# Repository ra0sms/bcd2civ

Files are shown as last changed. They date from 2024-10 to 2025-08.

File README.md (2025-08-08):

## Converter Yaesu BCD to Icom CI-V band data

A simple board is based on risk-v MCU CH32V003F4P6. 

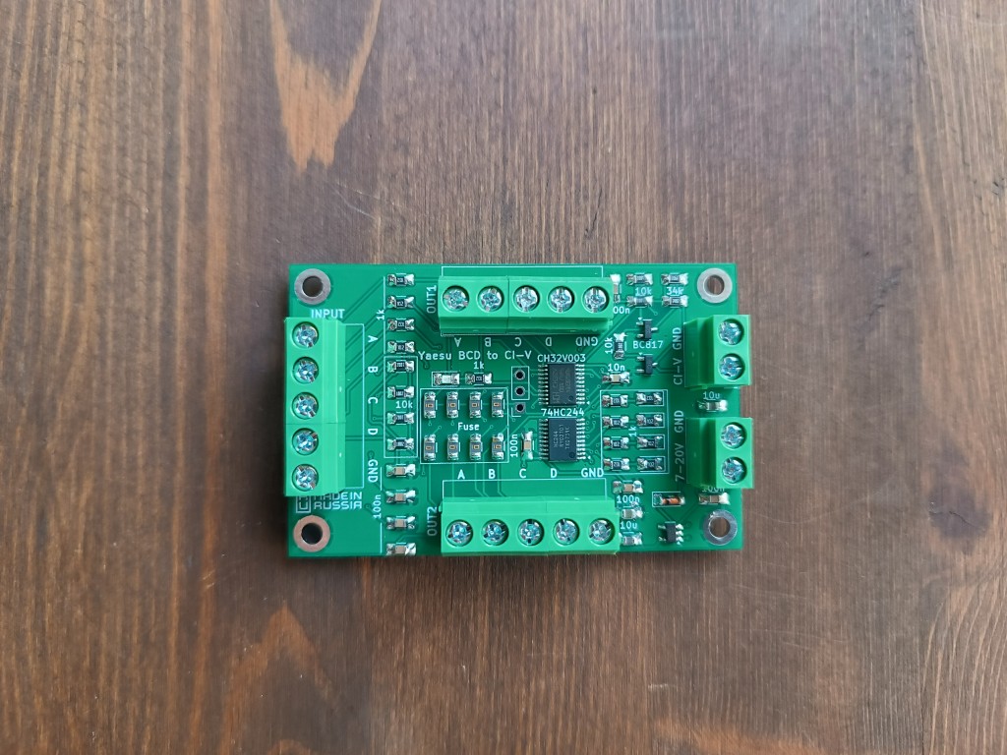
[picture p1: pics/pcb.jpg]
pcb


* Dimensions: 70*45 mm
* Consumption current: 20 mA
* Power supply: from 7 to 20VDC
* CI-V address: 0x7A
* Baud rate for EW3MM tuner: 9600 kb/s
* Baud rate for DJ0ABR controller: 4800 kb/s

[Firmware for EU3MM tuner](code/obj/bcd2civ_tuner.hex)

[Firmware for DJ0ABR controller](code/obj/bcd2civ_dj0abr.hex)

More information - https://ra0sms.com/bcd2civ

### Yaesu BCD band data:

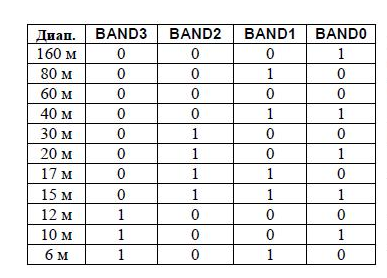
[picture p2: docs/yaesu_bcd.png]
yaseu_bcd


### Schematic:

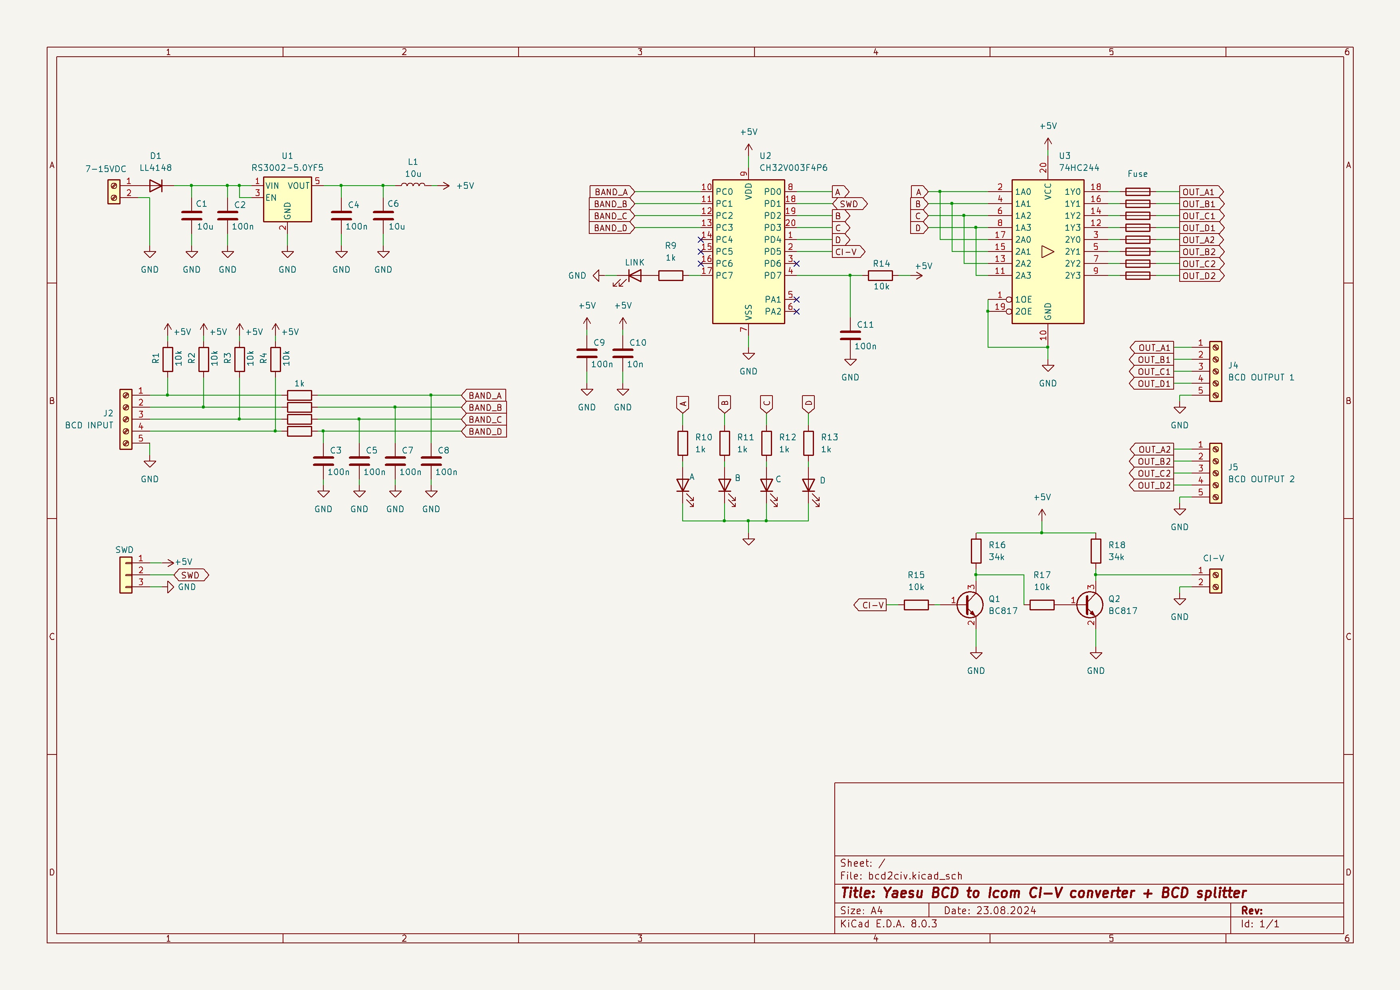
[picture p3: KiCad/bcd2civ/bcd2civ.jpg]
bcd2civ


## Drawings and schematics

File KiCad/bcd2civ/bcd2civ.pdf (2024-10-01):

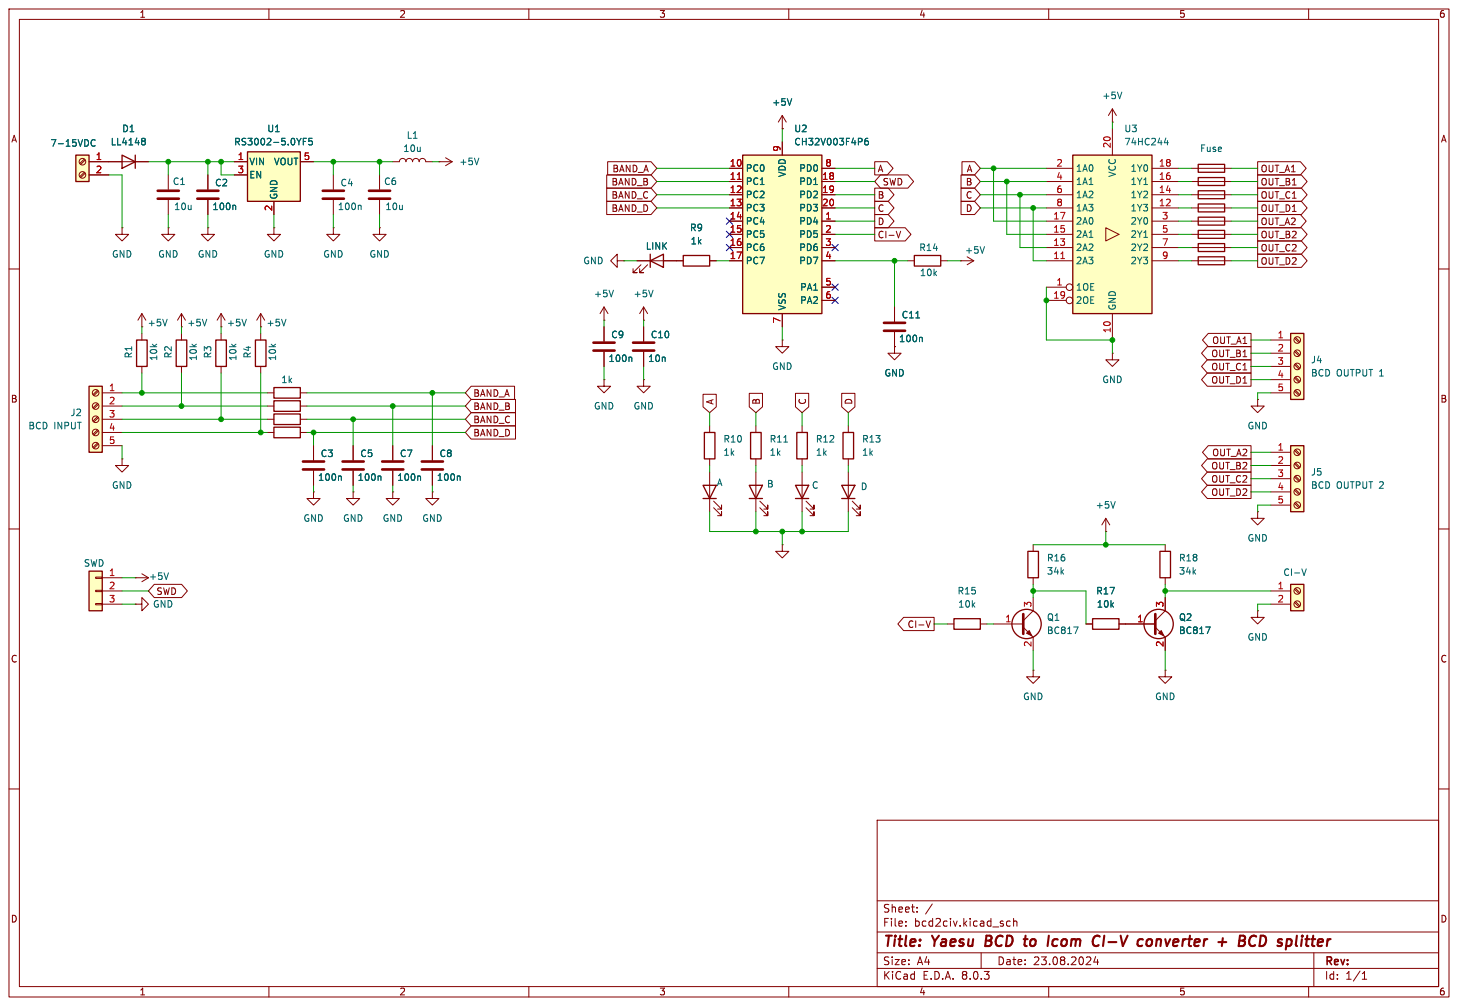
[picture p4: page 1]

Id: 1/1 Title: Yaesu BCD to Icom CI-V converter + BCD splitter File: bcd2civ.kicad_sch Sheet: /

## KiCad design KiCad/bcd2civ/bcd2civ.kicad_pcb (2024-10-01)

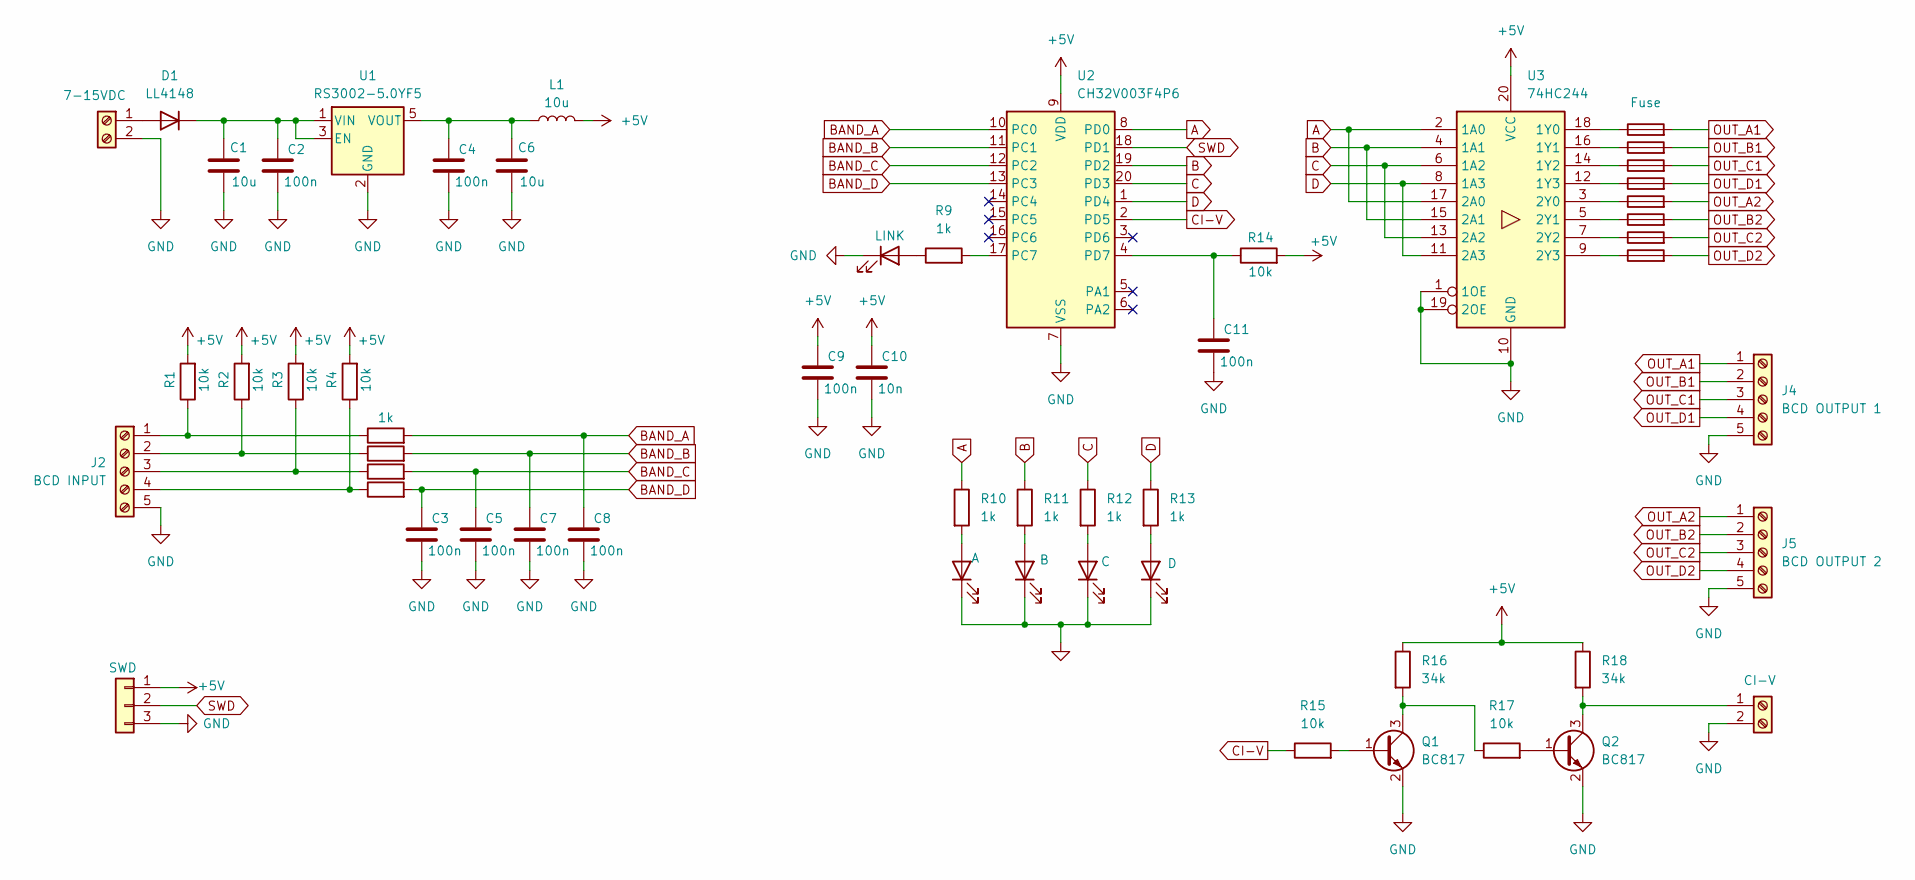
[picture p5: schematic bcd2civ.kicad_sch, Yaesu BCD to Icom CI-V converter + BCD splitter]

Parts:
C1, C6: 10u; C_1206_3216Metric_Pad1.33x1.80mm_HandSolder
C2, C3, C4, C5, C7, C8, C9, C11: 100n; C_1206_3216Metric_Pad1.33x1.80mm_HandSolder
C10: 10n; C_1206_3216Metric_Pad1.33x1.80mm_HandSolder
D1: LL4148; D_MiniMELF
D2: LINK; LED_1206_3216Metric
D3: A; LED_1206_3216Metric
D4: B; LED_1206_3216Metric
D5: C; LED_1206_3216Metric
D6: D; LED_1206_3216Metric
F1, F2, F3, F4, F5, F6, F7, F8: Fuse; R_1206_3216Metric
J1: 7-15VDC; TerminalBlock_MetzConnect_Type055_RT01502HDWU_1x02_P5.00mm_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
J2: BCD INPUT; TerminalBlock_MetzConnect_Type011_RT05505HBWC_1x05_P5.00mm_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
J3: SWD; PinSocket_1x03_P2.54mm_Vertical
J4: BCD OUTPUT 1; TerminalBlock_MetzConnect_Type011_RT05505HBWC_1x05_P5.00mm_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
J5: BCD OUTPUT 2; TerminalBlock_MetzConnect_Type011_RT05505HBWC_1x05_P5.00mm_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
J6: CI-V; TerminalBlock_MetzConnect_Type055_RT01502HDWU_1x02_P5.00mm_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
L1: 10u; L_1206_3216Metric
Q1, Q2: BC817; SOT-23
R1, R2, R3, R4, R14, R15, R17: 10k; R_1206_3216Metric
R5, R6, R7, R8, R9, R10, R11, R12, R13: 1k; R_1206_3216Metric
R16, R18: 34k; R_1206_3216Metric
U1: RS3002-5.0YF5; SOT-23-5
U2: CH32V003F4P6; TSSOP-20_4.4x6.5mm_P0.65mm
U3: 74HC244; TSSOP-20_4.4x6.5mm_P0.65mm

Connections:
+5V: C9.1, C10.1, J3.1, L1.2, R1.2, R2.2, R3.2, R4.2, R14.2, R16.1, R18.1, U2.9 (VDD), U3.20 (VCC)
A: R10.1, U2.8 (PD0), U3.2 (1A0), U3.17 (2A0)
B: R11.1, U2.19 (PD2), U3.4 (1A1), U3.15 (2A1)
BAND_A: C8.1, R5.2, U2.10 (PC0)
BAND_B: C7.1, R6.2, U2.11 (PC1)
BAND_C: C5.1, R7.2, U2.12 (PC2)
BAND_D: C3.1, R8.2, U2.13 (PC3)
C: R12.1, U2.20 (PD3), U3.6 (1A2), U3.13 (2A2)
CI-V: R15.1, U2.2 (PD5)
D: R13.1, U2.1 (PD4), U3.8 (1A3), U3.11 (2A3)
GND: C1.2, C2.2, C3.2, C4.2, C5.2, C6.2, C7.2, C8.2, C9.2, C10.2, C11.2, D2.1 (K), D3.1 (K), D4.1 (K), D5.1 (K), D6.1 (K), J1.2, J2.5, J3.3, J4.5, J5.5, J6.2, Q1.2 (E), Q2.2 (E), U1.2 (GND), U2.7 (VSS), U3.1 (1OE), U3.10 (GND), U3.19 (2OE)
unnamed: D1.2 (A), J1.1
unnamed: C1.1, C2.1, D1.1 (K), U1.1 (VIN), U1.3 (EN)
unnamed: D2.2 (A), R9.1
unnamed: D3.2 (A), R10.2
unnamed: D4.2 (A), R11.2
unnamed: D5.2 (A), R12.2
unnamed: D6.2 (A), R13.2
unnamed: J2.1, R1.1, R5.1
unnamed: J2.2, R2.1, R6.1
unnamed: J2.3, R3.1, R7.1
unnamed: J2.4, R4.1, R8.1
unnamed: J6.1, Q2.3 (C), R18.2
unnamed: Q1.1 (B), R15.2
unnamed: Q1.3 (C), R16.2, R17.1
unnamed: Q2.1 (B), R17.2
unnamed: C4.1, C6.1, L1.1, U1.5 (VOUT)
unnamed: R9.2, U2.17 (PC7)
unnamed: C11.1, R14.1, U2.4 (PD7)
unnamed: F1.1, U3.18 (1Y0)
unnamed: F2.1, U3.16 (1Y1)
unnamed: F3.1, U3.14 (1Y2)
unnamed: F4.1, U3.12 (1Y3)
unnamed: F5.1, U3.3 (2Y0)
unnamed: F6.1, U3.5 (2Y1)
unnamed: F7.1, U3.7 (2Y2)
unnamed: F8.1, U3.9 (2Y3)
OUT_A1: F1.2, J4.1
OUT_A2: F5.2, J5.1
OUT_B1: F2.2, J4.2
OUT_B2: F6.2, J5.2
OUT_C1: F3.2, J4.3
OUT_C2: F7.2, J5.3
OUT_D1: F4.2, J4.4
OUT_D2: F8.2, J5.4
SWD: J3.2, U2.18 (PD1)

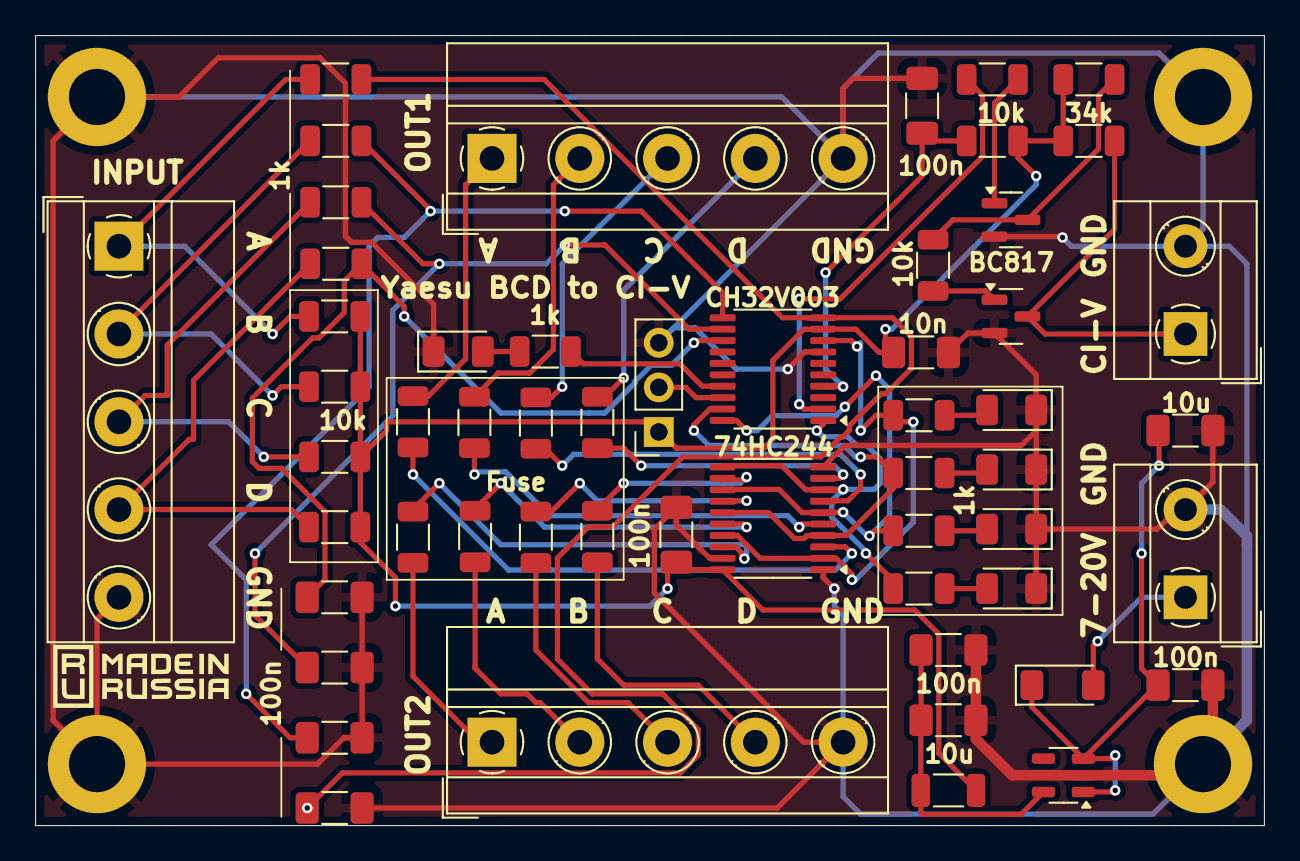
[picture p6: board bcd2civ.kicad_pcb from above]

Board: 2 copper layers, 70.0 x 45.0 mm, 55 parts (0 on the bottom side), 46 nets.

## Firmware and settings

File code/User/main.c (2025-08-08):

#include "debug.h"

#define LED_Pin GPIO_Pin_7
#define LED_GPIO_Port GPIOC
//**************
#define OUT_A GPIO_Pin_0
#define OUT_A_Port GPIOD
//***************
#define OUT_B GPIO_Pin_2
#define OUT_B_Port GPIOD
//***************
#define OUT_C GPIO_Pin_3
#define OUT_C_Port GPIOD
//***************
#define OUT_D GPIO_Pin_4
#define OUT_D_Port GPIOD
//**************
#define IN_A GPIO_Pin_0
#define IN_A_Port GPIOC
//***************
#define IN_B GPIO_Pin_1
#define IN_B_Port GPIOC
//***************
#define IN_C GPIO_Pin_2
#define IN_C_Port GPIOC
//***************
#define IN_D GPIO_Pin_3
#define IN_D_Port GPIOC
//***************

#define UART_SPEED 4800
#define CIV_ADDR 0x7A

int band = 0;


vu8 delay_ms = 0;

void USARTx_CFG(void)
{
    GPIO_InitTypeDef  GPIO_InitStructure = {0};
    USART_InitTypeDef USART_InitStructure = {0};
    NVIC_InitTypeDef  NVIC_InitStructure = {0};

    RCC_APB2PeriphClockCmd(RCC_APB2Periph_GPIOD | RCC_APB2Periph_USART1, ENABLE);

    /* USART1 TX-->D.5   RX-->D.6 */
    GPIO_InitStructure.GPIO_Pin = GPIO_Pin_5;
    GPIO_InitStructure.GPIO_Speed = GPIO_Speed_50MHz;
    GPIO_InitStructure.GPIO_Mode = GPIO_Mode_AF_PP;
    GPIO_Init(GPIOD, &GPIO_InitStructure);
    GPIO_InitStructure.GPIO_Pin = GPIO_Pin_6;
    GPIO_InitStructure.GPIO_Mode = GPIO_Mode_IN_FLOATING;
    GPIO_Init(GPIOD, &GPIO_InitStructure);

    USART_InitStructure.USART_BaudRate = UART_SPEED;
    USART_InitStructure.USART_WordLength = USART_WordLength_8b;
    USART_InitStructure.USART_StopBits = USART_StopBits_1;
    USART_InitStructure.USART_Parity = USART_Parity_No;
    USART_InitStructure.USART_HardwareFlowControl = USART_HardwareFlowControl_None;
    USART_InitStructure.USART_Mode = USART_Mode_Tx; //| USART_Mode_Rx;

    USART_Init(USART1, &USART_InitStructure);
    //USART_ITConfig(USART1, USART_IT_RXNE, ENABLE);

    NVIC_InitStructure.NVIC_IRQChannel = USART1_IRQn;
    NVIC_InitStructure.NVIC_IRQChannelPreemptionPriority = 0;
    NVIC_InitStructure.NVIC_IRQChannelSubPriority = 1;
    NVIC_InitStructure.NVIC_IRQChannelCmd = ENABLE;
    NVIC_Init(&NVIC_InitStructure);;

    USART_Cmd(USART1, ENABLE);
}

void Timer2_INIT(u16 arr, u16 psc)
{
    TIM_TimeBaseInitTypeDef TIMBase_InitStruct;
    NVIC_InitTypeDef NVIC_InitStruct;

    RCC_APB1PeriphClockCmd(RCC_APB1Periph_TIM2, ENABLE);

    TIMBase_InitStruct.TIM_Period = arr;
    TIMBase_InitStruct.TIM_CounterMode = TIM_CounterMode_Up;
    TIMBase_InitStruct.TIM_Prescaler = psc;
    TIMBase_InitStruct.TIM_ClockDivision = TIM_CKD_DIV1;
    TIM_TimeBaseInit(TIM2, &TIMBase_InitStruct);

    TIM_ITConfig(TIM2, TIM_IT_Update, ENABLE);

    NVIC_InitStruct.NVIC_IRQChannel = TIM2_IRQn;
    NVIC_InitStruct.NVIC_IRQChannelPreemptionPriority = 5;
    NVIC_InitStruct.NVIC_IRQChannelSubPriority = 5;
    NVIC_InitStruct.NVIC_IRQChannelCmd = ENABLE;
    NVIC_Init(&NVIC_InitStruct);
    TIM_Cmd(TIM2, ENABLE);
}

void GPIO_INIT(void)
{
    GPIO_InitTypeDef GPIO_InitStructure = {0};
    RCC_APB2PeriphClockCmd(RCC_APB2Periph_GPIOC, ENABLE);
    RCC_APB2PeriphClockCmd(RCC_APB2Periph_GPIOD, ENABLE);

    GPIO_InitStructure.GPIO_Pin = LED_Pin;
    GPIO_InitStructure.GPIO_Mode = GPIO_Mode_Out_PP;
    GPIO_InitStructure.GPIO_Speed = GPIO_Speed_50MHz;
    GPIO_Init(LED_GPIO_Port, &GPIO_InitStructure);

    GPIO_InitStructure.GPIO_Pin = OUT_A;
    GPIO_InitStructure.GPIO_Mode = GPIO_Mode_Out_PP;
    GPIO_InitStructure.GPIO_Speed = GPIO_Speed_50MHz;
    GPIO_Init(OUT_A_Port, &GPIO_InitStructure);

    GPIO_InitStructure.GPIO_Pin = OUT_B;
    GPIO_InitStructure.GPIO_Mode = GPIO_Mode_Out_PP;
    GPIO_InitStructure.GPIO_Speed = GPIO_Speed_50MHz;
    GPIO_Init(OUT_B_Port, &GPIO_InitStructure);

    GPIO_InitStructure.GPIO_Pin = OUT_C;
    GPIO_InitStructure.GPIO_Mode = GPIO_Mode_Out_PP;
    GPIO_InitStructure.GPIO_Speed = GPIO_Speed_50MHz;
    GPIO_Init(OUT_C_Port, &GPIO_InitStructure);

    GPIO_InitStructure.GPIO_Pin = OUT_D;
    GPIO_InitStructure.GPIO_Mode = GPIO_Mode_Out_PP;
    GPIO_InitStructure.GPIO_Speed = GPIO_Speed_50MHz;
    GPIO_Init(OUT_D_Port, &GPIO_InitStructure);

    GPIO_InitStructure.GPIO_Pin = IN_A;
    GPIO_InitStructure.GPIO_Mode = GPIO_Mode_IPU;
    GPIO_InitStructure.GPIO_Speed = GPIO_Speed_50MHz;
    GPIO_Init(IN_A_Port, &GPIO_InitStructure);

    GPIO_InitStructure.GPIO_Pin = IN_B;
    GPIO_InitStructure.GPIO_Mode = GPIO_Mode_IPU;
    GPIO_InitStructure.GPIO_Speed = GPIO_Speed_50MHz;
    GPIO_Init(IN_B_Port, &GPIO_InitStructure);

    GPIO_InitStructure.GPIO_Pin = IN_C;
    GPIO_InitStructure.GPIO_Mode = GPIO_Mode_IPU;
    GPIO_InitStructure.GPIO_Speed = GPIO_Speed_50MHz;
    GPIO_Init(IN_C_Port, &GPIO_InitStructure);

    GPIO_InitStructure.GPIO_Pin = IN_D;
    GPIO_InitStructure.GPIO_Mode = GPIO_Mode_IPU;
    GPIO_InitStructure.GPIO_Speed = GPIO_Speed_50MHz;
    GPIO_Init(IN_D_Port, &GPIO_InitStructure);

	GPIO_InitStructure.GPIO_Pin = GPIO_Pin_7;
    GPIO_InitStructure.GPIO_Mode = GPIO_Mode_IPU;
    GPIO_InitStructure.GPIO_Speed = GPIO_Speed_50MHz;
    GPIO_Init(GPIOD, &GPIO_InitStructure);

    Delay_Ms(200);

    GPIO_WriteBit(OUT_A_Port, OUT_A, Bit_SET);
    GPIO_WriteBit(OUT_B_Port, OUT_B, Bit_SET);
    GPIO_WriteBit(OUT_C_Port, OUT_C, Bit_SET);
    GPIO_WriteBit(OUT_D_Port, OUT_D, Bit_SET);

}

void SendMode(){
	Delay_Ms(2);
	USART_SendData(USART1, 0xFE);
	Delay_Ms(2);
	USART_SendData(USART1, 0xFE);
	Delay_Ms(2);
	USART_SendData(USART1, 0xE0);
	Delay_Ms(2);
	USART_SendData(USART1, 0x7A);
	Delay_Ms(2);
	USART_SendData(USART1, 0x04);
	Delay_Ms(2);
	USART_SendData(USART1, 0x01);
	Delay_Ms(2);
	USART_SendData(USART1, 0x01);
	Delay_Ms(2);
	USART_SendData(USART1, 0xFD);
	Delay_Ms(2);
}

void SendBandData(int band) {
    const uint8_t prefix[] = {0xFE, 0xFE, 0xE0, CIV_ADDR, 0x03, 0x00};
    uint8_t band_data[3] = {0}; 
    switch (band) {
        case 160: band_data[0] = 0x00; band_data[1] = 0x84; band_data[2] = 0x01; break;
        case 80:  band_data[0] = 0x30; band_data[1] = 0x57; band_data[2] = 0x03; break;
        case 60:  band_data[0] = 0x00; band_data[1] = 0x36; band_data[2] = 0x05; break;
        case 40:  band_data[0] = 0x40; band_data[1] = 0x07; band_data[2] = 0x07; break;
        case 30:  band_data[0] = 0x60; band_data[1] = 0x13; band_data[2] = 0x10; break;
        case 20:  band_data[0] = 0x40; band_data[1] = 0x07; band_data[2] = 0x14; break;
        case 17:  band_data[0] = 0x00; band_data[1] = 0x10; band_data[2] = 0x18; break;
        case 15:  band_data[0] = 0x40; band_data[1] = 0x07; band_data[2] = 0x21; break;
        case 12:  band_data[0] = 0x50; band_data[1] = 0x91; band_data[2] = 0x24; break;
        case 10:  band_data[0] = 0x40; band_data[1] = 0x07; band_data[2] = 0x28; break;
        case 6:   band_data[0] = 0x80; band_data[1] = 0x31; band_data[2] = 0x50; break;
        default: return; // Unknown band
    }
    for (int i = 0; i < sizeof(prefix); i++) {
        USART_SendData(USART1, prefix[i]);
        Delay_Ms(2);
    }
    for (int i = 0; i < 3; i++) {
        USART_SendData(USART1, band_data[i]);
        Delay_Ms(2);
    }
    USART_SendData(USART1, 0x00);
    Delay_Ms(2);
    USART_SendData(USART1, 0xFD);
}

int ReadBand (){
	Delay_Ms(10);
	int a = 0;
	int b = 0;
	int c = 0;
	int d = 0;
	a = GPIO_ReadInputDataBit(IN_A_Port, IN_A);
	b = GPIO_ReadInputDataBit(IN_B_Port, IN_B);
	c = GPIO_ReadInputDataBit(IN_C_Port, IN_C);
	d = GPIO_ReadInputDataBit(IN_D_Port, IN_D);
	if (a && !b && !c && !d) return 160;
	if (!a && b && !c && !d) return 80;
	if (!a && !b && !c && !d) return 60;
	if (a &&  b && !c && !d) return 40;
	if (!a && !b && c && !d) return 30;
	if (a && !b && c && !d) return 20;
	if (!a && b && c && !d) return 17;
	if (a && b && c && !d) return 15;
	if (!a && !b && !c && d) return 12;
	if (a && !b && !c && d) return 10;
	if (!a && b && !c && d) return 6;
	if (a && b && c && d) return 0;
	return 0;
}

void SetOuts (int band){
	if (band == 160){
		GPIO_WriteBit(OUT_A_Port, OUT_A, Bit_SET);
	    GPIO_WriteBit(OUT_B_Port, OUT_B, Bit_RESET);
		GPIO_WriteBit(OUT_C_Port, OUT_C, Bit_RESET);
		GPIO_WriteBit(OUT_D_Port, OUT_D, Bit_RESET);
	}
	if (band == 80){
		GPIO_WriteBit(OUT_A_Port, OUT_A, Bit_RESET);
	    GPIO_WriteBit(OUT_B_Port, OUT_B, Bit_SET);
		GPIO_WriteBit(OUT_C_Port, OUT_C, Bit_RESET);
		GPIO_WriteBit(OUT_D_Port, OUT_D, Bit_RESET);
	}
	if (band == 60){
		GPIO_WriteBit(OUT_A_Port, OUT_A, Bit_RESET);
	    GPIO_WriteBit(OUT_B_Port, OUT_B, Bit_RESET);
		GPIO_WriteBit(OUT_C_Port, OUT_C, Bit_RESET);
		GPIO_WriteBit(OUT_D_Port, OUT_D, Bit_RESET);
	}
	if (band == 40){
		GPIO_WriteBit(OUT_A_Port, OUT_A, Bit_SET);
	    GPIO_WriteBit(OUT_B_Port, OUT_B, Bit_SET);
		GPIO_WriteBit(OUT_C_Port, OUT_C, Bit_RESET);
		GPIO_WriteBit(OUT_D_Port, OUT_D, Bit_RESET);
	}
	if (band == 30){
		GPIO_WriteBit(OUT_A_Port, OUT_A, Bit_RESET);
	    GPIO_WriteBit(OUT_B_Port, OUT_B, Bit_RESET);
		GPIO_WriteBit(OUT_C_Port, OUT_C, Bit_SET);
		GPIO_WriteBit(OUT_D_Port, OUT_D, Bit_RESET);
	}
	if (band == 20){
		GPIO_WriteBit(OUT_A_Port, OUT_A, Bit_SET);
	    GPIO_WriteBit(OUT_B_Port, OUT_B, Bit_RESET);
		GPIO_WriteBit(OUT_C_Port, OUT_C, Bit_SET);
		GPIO_WriteBit(OUT_D_Port, OUT_D, Bit_RESET);
	}
	if (band == 17){
		GPIO_WriteBit(OUT_A_Port, OUT_A, Bit_RESET);
	    GPIO_WriteBit(OUT_B_Port, OUT_B, Bit_SET);
		GPIO_WriteBit(OUT_C_Port, OUT_C, Bit_SET);
		GPIO_WriteBit(OUT_D_Port, OUT_D, Bit_RESET);
	}
	if (band == 15){
		GPIO_WriteBit(OUT_A_Port, OUT_A, Bit_SET);
	    GPIO_WriteBit(OUT_B_Port, OUT_B, Bit_SET);
		GPIO_WriteBit(OUT_C_Port, OUT_C, Bit_SET);
		GPIO_WriteBit(OUT_D_Port, OUT_D, Bit_RESET);
	}
	if (band == 12){
		GPIO_WriteBit(OUT_A_Port, OUT_A, Bit_RESET);
	    GPIO_WriteBit(OUT_B_Port, OUT_B, Bit_RESET);
		GPIO_WriteBit(OUT_C_Port, OUT_C, Bit_RESET);
		GPIO_WriteBit(OUT_D_Port, OUT_D, Bit_SET);
	}
	if (band == 10){
		GPIO_WriteBit(OUT_A_Port, OUT_A, Bit_SET);
	    GPIO_WriteBit(OUT_B_Port, OUT_B, Bit_RESET);
		GPIO_WriteBit(OUT_C_Port, OUT_C, Bit_RESET);
		GPIO_WriteBit(OUT_D_Port, OUT_D, Bit_SET);
	}
	if (band == 6){
		GPIO_WriteBit(OUT_A_Port, OUT_A, Bit_RESET);
	    GPIO_WriteBit(OUT_B_Port, OUT_B, Bit_SET);
		GPIO_WriteBit(OUT_C_Port, OUT_C, Bit_RESET);
		GPIO_WriteBit(OUT_D_Port, OUT_D, Bit_SET);
	}

	if (band == 0){
		GPIO_WriteBit(OUT_A_Port, OUT_A, Bit_SET);
	    GPIO_WriteBit(OUT_B_Port, OUT_B, Bit_SET);
		GPIO_WriteBit(OUT_C_Port, OUT_C, Bit_SET);
		GPIO_WriteBit(OUT_D_Port, OUT_D, Bit_SET);
	}
}

int main(void)
{
    NVIC_PriorityGroupConfig(NVIC_PriorityGroup_1);
    SystemCoreClockUpdate();
    Delay_Init();
    GPIO_INIT();
    USARTx_CFG();
    Timer2_INIT(999, 23999);
    while(1)
    {
    	band = ReadBand();
    	SendBandData(band);
    	SetOuts(band);
    	Delay_Ms(200);
    }
}

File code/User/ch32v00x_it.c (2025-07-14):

/********************************** (C) COPYRIGHT *******************************
 * File Name          : ch32v00x_it.c
 * Author             : WCH
 * Version            : V1.0.0
 * Date               : 2023/12/25
 * Description        : Main Interrupt Service Routines.
*********************************************************************************
* Copyright (c) 2021 Nanjing Qinheng Microelectronics Co., Ltd.
* Attention: This software (modified or not) and binary are used for 
* microcontroller manufactured by Nanjing Qinheng Microelectronics.
*******************************************************************************/
#include <ch32v00x_it.h>

void NMI_Handler(void) __attribute__((interrupt("WCH-Interrupt-fast")));
void HardFault_Handler(void) __attribute__((interrupt("WCH-Interrupt-fast")));

/*********************************************************************
 * @fn      NMI_Handler
 *
 * @brief   This function handles NMI exception.
 *
 * @return  none
 */
void NMI_Handler(void)
{
  while (1)
  {
  }
}

/*********************************************************************
 * @fn      HardFault_Handler
 *
 * @brief   This function handles Hard Fault exception.
 *
 * @return  none
 */
void HardFault_Handler(void)
{
  while (1)
  {
    NVIC_SystemReset();
  }
}

__attribute__((interrupt("WCH-Interrupt-fast")))
void TIM2_IRQHandler(void)
{
    static u8 j = 0;
    if (TIM_GetITStatus(TIM2, TIM_IT_Update) == SET)
    {
        TIM_ClearITPendingBit(TIM2, TIM_IT_Update);
        GPIO_WriteBit(GPIOC, GPIO_Pin_7, (j == 0) ? (j = Bit_SET) : (j = Bit_RESET));
    }
}
